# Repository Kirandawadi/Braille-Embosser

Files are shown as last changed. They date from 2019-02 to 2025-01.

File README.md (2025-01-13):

An autonomous device built with **AVR** and programmed in **C** that can convert any printed textbook into braille format using **Optical Character Recognition (OCR)** and custom-built hardware mechanism.

It won the 2nd runner up at **AT-HACKATHON 2018**.

**Demo Video:** [Link](https://1drv.ms/v/c/b3eb1096e4f4a3a8/Eaij9OSWEOsggLN66wAAAAABXvvN7yaE1aCTUCs381BpYw)

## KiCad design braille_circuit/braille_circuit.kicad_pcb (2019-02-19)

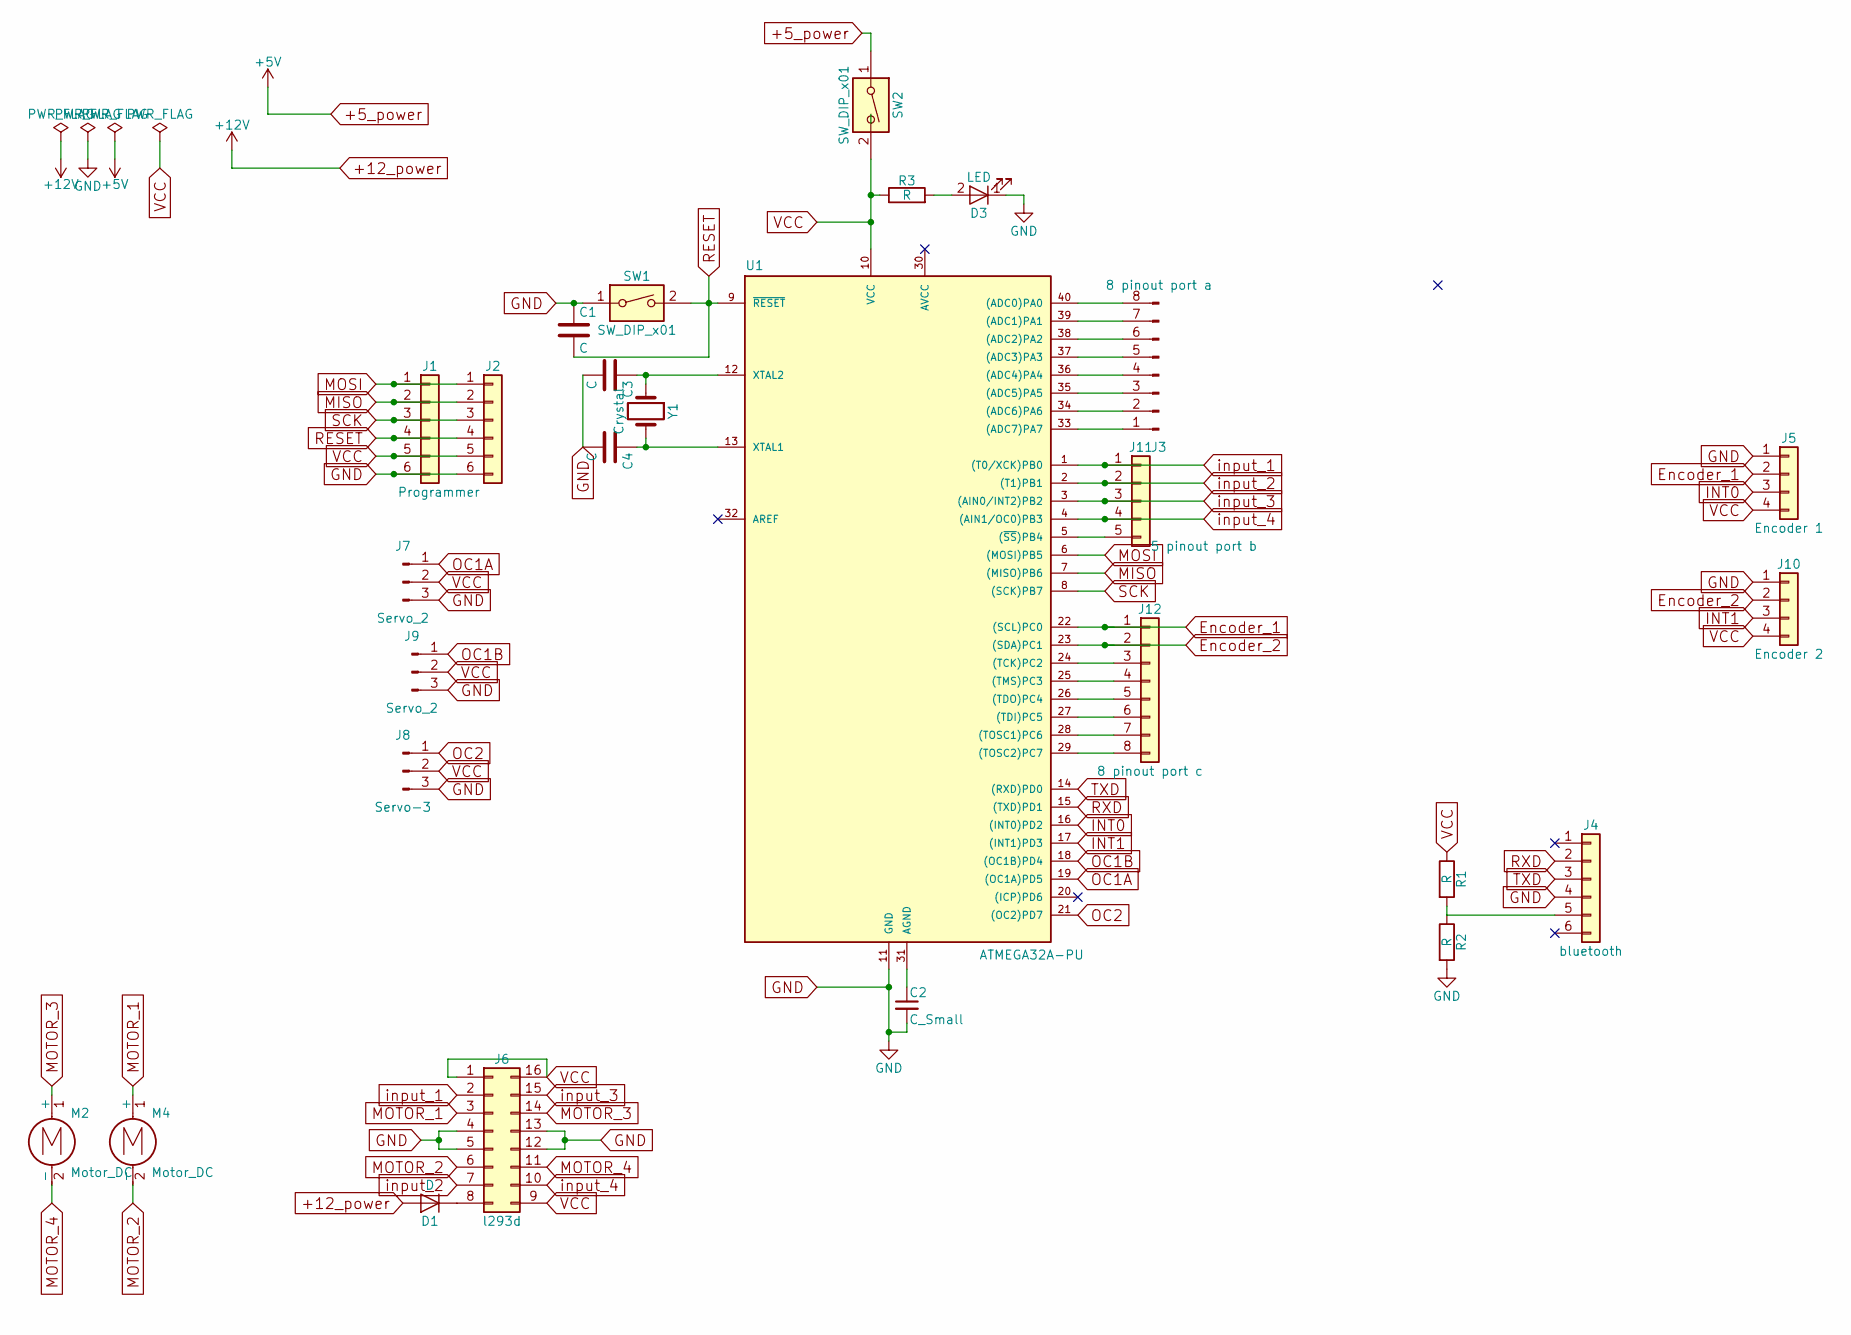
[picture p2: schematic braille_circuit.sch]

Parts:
C1, C3, C4: C; C_Disc_D3.0mm_W2.0mm_P2.50mm
C2: C_Small; C_Disc_D3.0mm_W2.0mm_P2.50mm
D1: D; D_5W_P10.16mm_Horizontal
D3: LED; LED_D5.0mm
J1, J2: Programmer; Pin_Header_Straight_1x06_Pitch2.54mm
J3: 8 pinout port a; Pin_Header_Straight_1x08_Pitch2.54mm
J4: bluetooth; Pin_Header_Straight_1x06_Pitch2.54mm
J5: Encoder 1; Pin_Header_Straight_1x04_Pitch2.54mm
J6: l293d; DIP-16_W7.62mm_Socket_LongPads
J7, J9: Servo_2; Pin_Header_Straight_1x03_Pitch2.54mm
J8: Servo-3; Pin_Header_Straight_1x03_Pitch2.54mm
J10: Encoder 2; Pin_Header_Straight_1x04_Pitch2.54mm
J11: 5 pinout port b; Pin_Header_Straight_1x05_Pitch2.54mm
J12: 8 pinout port c; Pin_Header_Straight_1x08_Pitch2.54mm
M2, M4: Motor_DC; TerminalBlock_Pheonix_MKDS1.5-2pol
R1, R2, R3: R; R_Axial_DIN0207_L6.3mm_D2.5mm_P10.16mm_Horizontal
SW1: SW_DIP_x01; SW_PUSH_6mm_h5mm
SW2: SW_DIP_x01; 6_pin_switch
U1: ATMEGA32A-PU; DIP-40_W15.24mm_LongPads
Y1: Crystal; Crystal_HC18-U_Vertical

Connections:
+5_power: SW2.1
+12_power: D1.2 (A)
Encoder_1: J5.2, J12.1, U1.22 ((SCL)PC0)
Encoder_2: J10.2, J12.2, U1.23 ((SDA)PC1)
GND: C1.1, C2.2, C3.2, C4.2, D3.1 (K), J1.6, J2.6, J4.4, J5.1, J6.4, J6.5, J6.12, J6.13, J7.3, J8.3, J9.3, J10.1, R2.2, SW1.1, U1.11 (GND)
INT0: J5.3, U1.16 ((INT0)PD2)
INT1: J10.3, U1.17 ((INT1)PD3)
MISO: J1.2, J2.2, U1.7 ((MISO)PB6)
MOSI: J1.1, J2.1, U1.6 ((MOSI)PB5)
MOTOR_1: J6.3, M4.1 (+)
MOTOR_2: J6.6, M4.2 (-)
MOTOR_3: J6.14, M2.1 (+)
MOTOR_4: J6.11, M2.2 (-)
unnamed: C2.1, U1.31 (AGND)
unnamed: C3.1, U1.12 (XTAL2), Y1.1
unnamed: C4.1, U1.13 (XTAL1), Y1.2
unnamed: D1.1 (K), J6.8
unnamed: D3.2 (A), R3.2
unnamed: J3.1, U1.33 ((ADC7)PA7)
unnamed: J3.2, U1.34 ((ADC6)PA6)
unnamed: J3.3, U1.35 ((ADC5)PA5)
unnamed: J3.4, U1.36 ((ADC4)PA4)
unnamed: J3.5, U1.37 ((ADC3)PA3)
unnamed: J3.6, U1.38 ((ADC2)PA2)
unnamed: J3.7, U1.39 ((ADC1)PA1)
unnamed: J3.8, U1.40 ((ADC0)PA0)
unnamed: J4.5, R1.2, R2.1
unnamed: J11.5, U1.5 ((~SS~)PB4)
unnamed: J12.3, U1.24 ((TCK)PC2)
unnamed: J12.4, U1.25 ((TMS)PC3)
unnamed: J12.5, U1.26 ((TDO)PC4)
unnamed: J12.6, U1.27 ((TDI)PC5)
unnamed: J12.7, U1.28 ((TOSC1)PC6)
unnamed: J12.8, U1.29 ((TOSC2)PC7)
OC1A: J7.1, U1.19 ((OC1A)PD5)
OC1B: J9.1, U1.18 ((OC1B)PD4)
OC2: J8.1, U1.21 ((OC2)PD7)
RESET: C1.2, J1.4, J2.4, SW1.2, U1.9 (~RESET)
RXD: J4.2, U1.15 ((TXD)PD1)
SCK: J1.3, J2.3, U1.8 ((SCK)PB7)
TXD: J4.3, U1.14 ((RXD)PD0)
VCC: J1.5, J2.5, J5.4, J6.1, J6.9, J6.16, J7.2, J8.2, J9.2, J10.4, R1.1, R3.1, SW2.2, U1.10 (VCC)
input_1: J6.2, J11.1, U1.1 ((T0/XCK)PB0)
input_2: J6.7, J11.2, U1.2 ((T1)PB1)
input_3: J6.15, J11.3, U1.3 ((AIN0/INT2)PB2)
input_4: J6.10, J11.4, U1.4 ((AIN1/OC0)PB3)

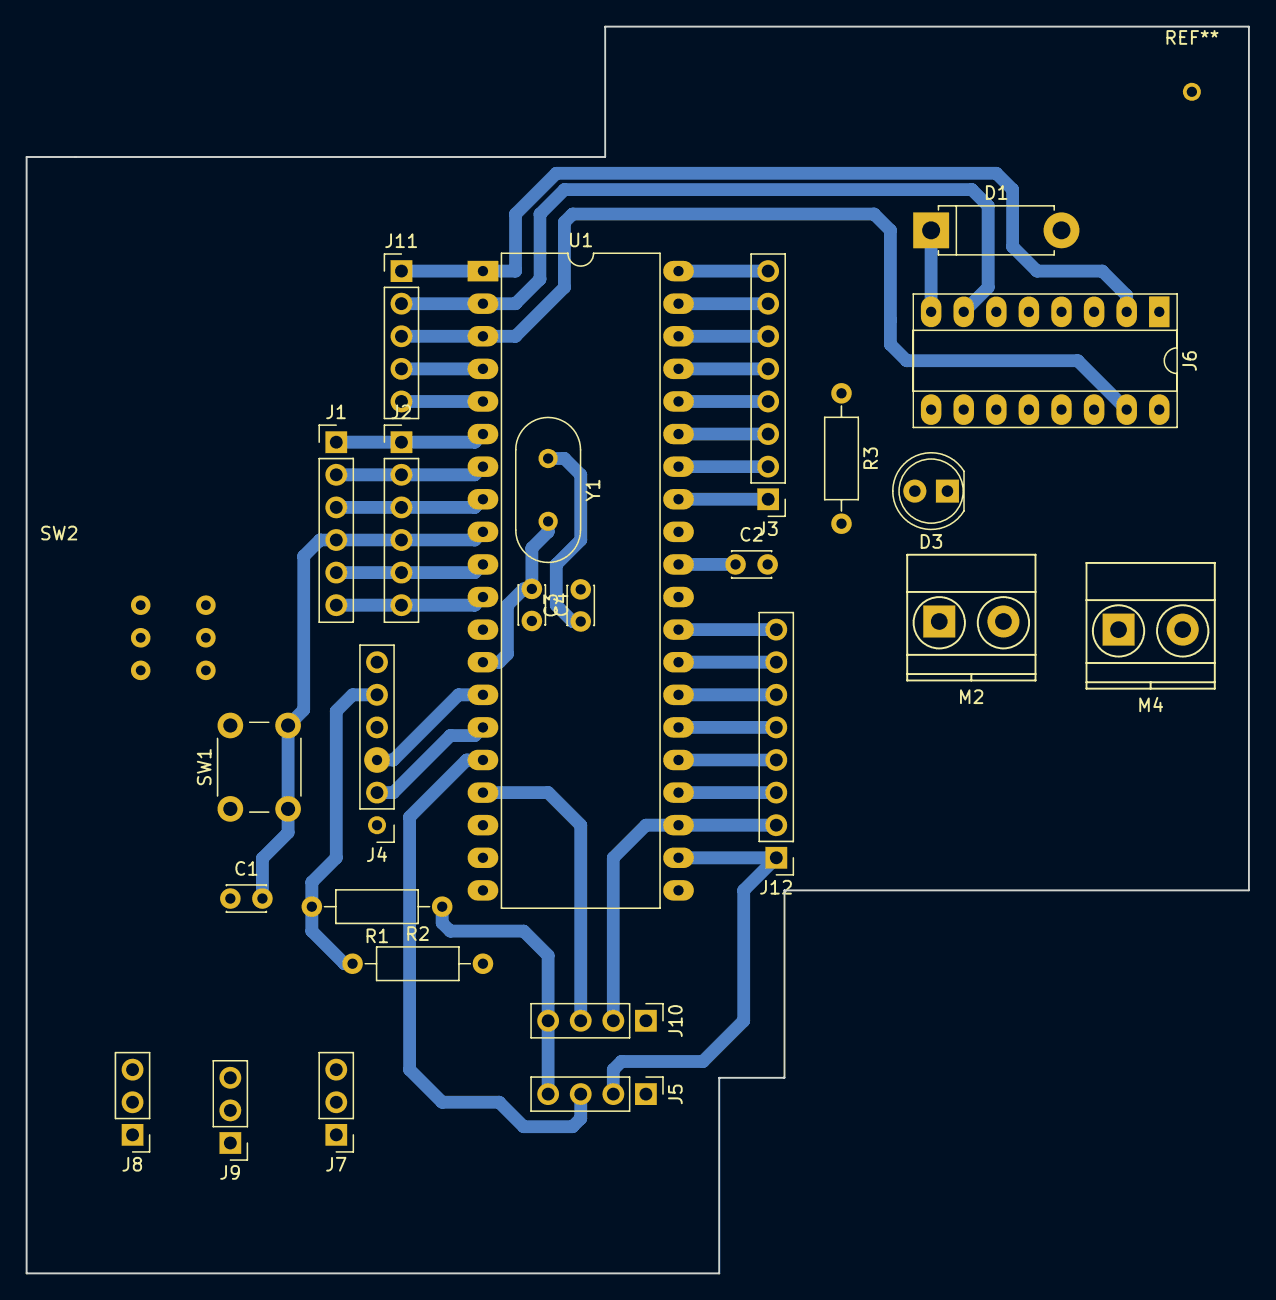
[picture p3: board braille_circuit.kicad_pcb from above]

Board: 2 copper layers, 95.2 x 97.2 mm, 27 parts (0 on the bottom side), 44 nets.

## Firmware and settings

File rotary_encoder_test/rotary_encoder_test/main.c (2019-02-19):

/*
 * opto_test.c
 *
 * Created: 5/13/2018 8:03:57 AM
 * Author : Acer-PC
 */ 

#define F_CPU 16000000UL
#include <avr/io.h>
#include <avr/interrupt.h>
#include <util/delay.h>
#include "USART_RS232_H_file.h"
#include "motors.h"
#include "braille_codes.h"
#include <stdio.h>
#include <stdlib.h>	
#include <ctype.h>
#include <stdlib.h>
#include <util/delay.h>
#define bit_is_set(sfr,bit) (_SFR_BYTE(sfr) & _BV(bit))
#define bit_is_clear(sfr,bit) (!(_SFR_BYTE(sfr) & _BV(bit)))

char buffer[20], float_[10];                            //used in converting number to string and then transmitting via bluetooth
char buff_[100]={0};										//used in USART
volatile double linear_counter,rotary_counter;
int test=0;
long int pulse_width=0,pre=0;
int num=0;
int rec=0,receive=0,converted;
int j=0 ;
uint8_t tem=0;
double linear_position=2;
int volatile punch_pin[6] = {0,0,0,0,0,0};

ISR(INT0_vect)				//used by linear
{
		if(((bit_is_clear(PINC,PC0))==(bit_is_clear(PIND,PD2)))||((bit_is_set(PINC,PC0))==(bit_is_set(PIND,PD2))))
		{
			--linear_counter;
			
		}
		else
		{
			++linear_counter;
		}

}

ISR(INT1_vect)			//used by rotary
{
	
	if(((bit_is_clear(PINB,PB0))==(bit_is_clear(PIND,PD3)))||((bit_is_set(PINB,PB0))==(bit_is_set(PIND,PD3))))
	{
		
		++rotary_counter;
		
	}
	else
	{
		--rotary_counter;
	}
	
}

ISR(USART_RXC_vect)
{

	/*int received = UDR;

	if(received =='a')
	{
		go_rotary_forward();
	}

	if(received == 'b')
	{
		PORTB = 0x00;
				
	}
	
		if(received =='q')
		{
			go_rotary_forward();
		}

		if(received == 'w')
		{
			go_rotary_backward();
		}
*/


}


int main(void)
{
	DDRA |= 1<<PINA1;			//Controlling relay through this pin
	PORTA |= 1<<PINA1;
	DDRC &= ~(1<<PINC0);			//making PINC0 as interrupt taker for INT0
	//DDRD &= ~(1<<PIND3);			//making INT1 as input
	DDRB = 0xFF;			//All pins are output for Motors 1 and 2
	sei();
	USART_Init(38400);
	GICR = (1<<INT0)|(1<<INT1);				//|(1<<INT2)
    MCUCR = (1<<ISC00)|(1<<ISC10);			//Both INT0 and INT1 interrupt on both edges(rising and falling)
	//MCUCSR = 1<<ISC2;						//INT2 on rising edge
	//TCCR1B |= (1<<CS12)|(1<<CS10);
	
	//double i=30;
	
	_delay_ms(2000);
 	set_position_cm(linear_position);
 	USART_SendString("Calibrating your system....\n");
	
	
	print_VISION();
	//vertical_dots();
	
	
	/*
	Braille_Print_character('a');
	//_delay_ms(2000);
	Braille_Print_character('b');
	//_delay_ms(2000);
	Braille_Print_character('c');
	//_delay_ms(2000);*/

   
		   while (1) 
		{
// 			
// 			set_position_cm(4);
// 			_delay_ms(500);
// 			set_position_cm(2);
// 			_delay_ms(500);
// 			set_position_cm(6);
// 			_delay_ms(500);
// 			set_position_cm(2);
// 			_delay_ms(500);
// 			
			
			// _delay_ms(100);
// 		
// 		go_linear_forward();
// 		_delay_ms(500);
// 		go_linear_backward();
// 		_delay_ms(500);
// 		
// 	go_rotary_forward();
// 	_delay_ms(500);
// 	rotary_halt();
// 	_delay_ms(500);
// // 			
// 		 for(int i=3;i<30;i++)
// 			 {
// 				 	set_position_cm(i);
// 					 _delay_ms(500);
// 			 }
		}


	return 0;
}




				/**********BACKUP*****************/

// go_rotary_forward();
// 
// dtostrf(i, 3, 2, float_ );
// sprintf(buffer,"Given Value= %s\t",float_);
// USART_SendString(buffer);
// 
// dtostrf(rotary_counter, 3, 2, float_ );
// sprintf(buffer,"Counter value= %s\n",float_);
// USART_SendString(buffer);
// 
// if(rotary_counter>=1086)
// {
// 	rotary_halt();
// 	break;
// }


// 
// 
// void toggle_two_time()
// {
// 	for(int i=0;i<4;i++)
// 	{
// 		PORTB^=1<<PINB0;
// 		_delay_ms(400);
// 	}
// 	
// }
// 
// void toggle_three_time()
// {
// 	for(int i=0;i<6;i++)
// 	{
// 		PORTB^=1<<PINB0;
// 		_delay_ms(400);
// 		
// 		
// 	}
// 	
// }
// 
// 
// ISR(USART_RXC_vect)
// {
// 
// 	int received = UDR;
// 	
// 	if(received =='a')
// 	{
// 		toggle_two_time();
// 	}
// 	
// 	if(received == 'b')
// 	{
// 		toggle_three_time();
// 	}
// 	
// 	
// 
// }

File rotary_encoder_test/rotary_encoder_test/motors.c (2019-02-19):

/*
 * motor_functions.c
 *
 * Created: 6/2/2018 9:56:29 PM
 *  Author: Kiran Dawadi
 */
 
#define F_CPU 16000000UL
#include <avr/io.h>
#include "motors.h"
#include <util/delay.h>

extern volatile double linear_counter,rotary_counter;

void punch(void)
{
	PORTA &= ~(1<<PINA1);
	_delay_ms(500);
	PORTA = 1<<PINA1;				//PINA1 is controlling the punch pin
}

void go_linear_forward(void)
{

	PORTB = (1<<LINEAR_MOTOR_1);
	
}

void go_linear_backward(void)
{
	PORTB = (1<<LINEAR_MOTOR_2);
	
}

void linear_halt(void)
{
	PORTB &= ~((1<<LINEAR_MOTOR_1)|(1<<LINEAR_MOTOR_2));
}

void go_rotary_forward(void)
{

	PORTB = (1<<ROTARY_MOTOR_1);
	
}

void paper_slide_forward(void)
{
	go_rotary_forward();
	_delay_ms(30);
	rotary_halt();
}

void paper_slide_backward(void)
{
	go_rotary_backward();
	_delay_ms(30);
	rotary_halt();
}



void go_rotary_backward(void)
{
	PORTB = (1<<ROTARY_MOTOR_2);
}

void rotary_halt(void)
{
	PORTB &= ~((1<<ROTARY_MOTOR_1)|(1<<ROTARY_MOTOR_2));
}



 void set_position_cm(double value)
 {
 	value = value*117;
	if(value>linear_counter)
	{
 	while( value > linear_counter)
 	{
 		go_linear_forward();
 	}
	}
	if(value<linear_counter)
	{
		while( value < linear_counter)
		{
			go_linear_backward();
		}	
	}
// 	 while(value<linear_counter)					//Test this (Not tested)
// 	 {
// 		 go_linear_backward();
// 	 }
//  	
 	linear_halt();
 		
 }



void set_position_degrees(double angle)
{
				
	while(angle > rotary_counter)
	{
			go_rotary_forward();
	}
	
	rotary_halt();

	
}

// void set_position_degrees(double angle)				//This is created as dummy
// {
// 	angle = angle*117;
// 	while(angle > rotary_counter)
// 	{
// 		go_rotary_forward();
// 	}
// 	
// 	rotary_halt();
// 
// 	
// }
